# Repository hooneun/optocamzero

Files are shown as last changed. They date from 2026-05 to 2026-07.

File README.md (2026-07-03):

# Optocam Zero

Optocam Zero is a Raspberry Pi Zero based compact digital camera made using off the shelf components. 

I designed Optocam Zero to have a very compact, carry everywhere and have fun sort of camera. As I was inspired by Kodak charmera and similar toy cameras, I wanted it to be feel playful, enjoyable and be intuitive to use. I also aimed to make it relatively easy to build so that others can also build one and have fun with it. That's why all the case parts are easily printable and for the electronics it uses off the shelf components that are easy to find.

exploded view

## Features
- Very compact and easy to carry in your pocket.
- Intuitive and simple camera interface and controls.
- Uses autofocus camera module.
- 8 photo filters included.
- Easy and fast image transfer through custom hotspot interface. Optimized both for mobile and desktop.
- Screen dimming when inactive to preserve battery.
- USB-C charging. Device can be used while charging.
- Interchangable battery.
- Off the shelf/ common components for the electronics.
- Fully 3D printed case parts (apart from fasteners).
- 3D printable TPU protective sleeve and lanyard design is available.
- **NEW** - GIF recording and playback.

<br>

## Specs
- **UPDATE** - Now boots in 5 seconds with the buildroot image.
- **UPDATE** - Consistent 25-30 fps camera preview on the screen.
- 2592x2592px Jpeg image capture. Image saves in the background while preview stays active.
- 240x240px 1.4 inch lcd display.
- Uses 14500 type li-ion battery.
- 70–80 minutes of use per charge.
- Dimensions: 51×71×18mm (excluding camera and screen bump)
  
<br>

## Sample Photos

 
 
 
 

<br>

## How to Build Optocam Zero?

Everything you need to build an Optocam Zero yourself is included in this repo.

All the 3d print files, Required parts list, and detailed step by step build guide can be found under the [hardware](hardware/) folder.

If you're considering building one, check the [BOM](hardware/BOM.md) to get an idea of the cost for required tools and parts.
Also, have a look at the [build guide](hardware/optocamzero-build-guide.pdf), it will give you a clear idea of what the build involves.

<br>

## Hardware

See the [hardware](hardware/) folder for:

- [Bill of materials](hardware/BOM.md).
- [Build guide](hardware/optocamzero-build-guide.pdf) (PDF).
- [Bambu Studio project files](hardware/print-ready/) ready to print for transparent PETG or PETG / PETG-CF.
- [Individual .stls](hardware/stls/) for camera parts.
- [CAD file](hardware/cad/optocamzero_V1.0.step) for customization.

<br>

## Software

See the [software](software/) folder for: 

- Optocam Zero code and installation guide.
- Camera controls information.

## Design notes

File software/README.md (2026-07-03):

# Optocam Zero Firmware Installation and Interface Controls

<br>

## Requirements

- Completed Optocam Zero with the correct components.
- Micro sd card (16GB or larger, A2 type recommended for best performance).
- A computer with internet access.

<br>

## Installation

**1. Download the firmware image**

Download the latest Optocam Zero image (`.img`) from the [releases page](https://github.com/dorukkumkumoglu/optocamzero/releases/latest).

**2. Flash the SD card**

Download Raspberry Pi Imager from [raspberrypi.com/software](https://www.raspberrypi.com/software/) and install it. Select **Raspberry Pi Zero 2W** as the device. Under **Choose OS**, scroll to the bottom and select **Use custom**, then pick the image file you just downloaded.

Select your SD card under **Choose Storage**, then click **Write**. If asked whether to apply OS customisation settings, choose **No**.

**3. First boot**

Insert the SD card into the Pi and power it on. The camera boots to the preview in about 5 seconds and is ready to use.

<br>

<br>

## Interface/ Controls

The device is turned on and off using the power switch on the right side. Reaching the camera preview after turning on the device takes 5 seconds.

Camera focus is set to continuous auto and cannot be adjusted manually. Camera shutter speed and ISO are set to auto and cannot be adjusted manually.

Currently, 8 different photo filters are included. You can switch between them. Color temperature can also be changed.

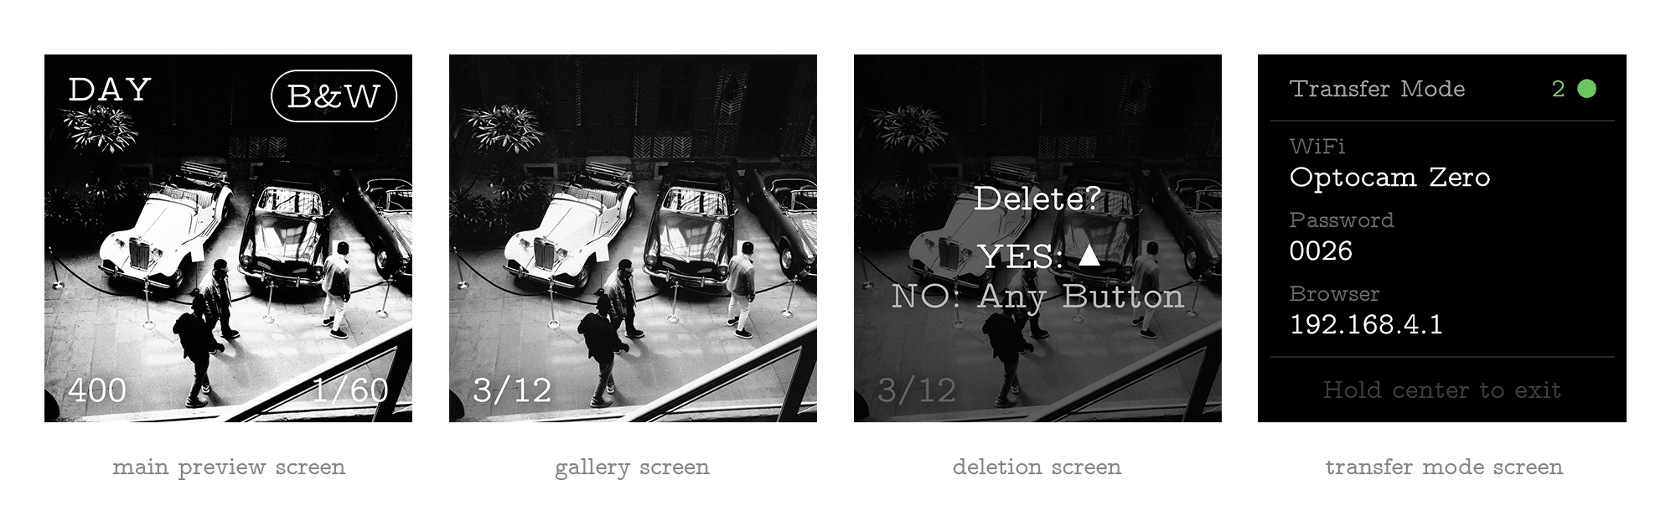
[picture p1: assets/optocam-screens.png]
Camera Screens


### Main camera preview screen controls
- Top left corner displays current color temperature (left-right joystick toggles between different color temperature modes).
- Top right corner displays current photo filter (up-down joystick toggles between different photo filters).
- Bottom left corner displays current ISO.
- Bottom right corner displays current shutter speed.
- A loading circle appears in the bottom center when an image is being saved. Wait for it to disappear before turning off the camera.
- A long press of the shutter button switches between GIF and Photo modes.
- In GIF mode, pressing the shutter button once captures a 10 frame GIF with a duration of 5 seconds. Pressing the shutter button again during capture cancels the recording.

### Gallery controls
- Center joystick button opens the gallery.
- The numbers in the bottom left corner display the photo count and the currently displayed photo number.
- Left-right joystick navigates between photos in the gallery.
- Push joystick up for photo deletion. A confirmation overlay will appear. Push up once more to confirm deletion. Press any other button on the device to cancel.
- To exit the gallery, press the center joystick button or the shutter button. This will return to the main camera preview immediately.

### Transfer mode (Hotspot)
Optocam Zero includes a hotspot mode and photo transfer interface optimized for both mobile and desktop use.
- To activate transfer mode, long press the center joystick button.
- Long press the center joystick button again to exit transfer mode.
- To transfer images, connect your phone or computer to the Wi-Fi network called **Optocam Zero** (find the password on the screen) and open **192.168.4.1** in a browser.
- The dot in the top right corner and the number next to it indicate how many devices are currently connected to the hotspot. The dot turns green when a device is connected.

### Transfer interface (External Device)
After opening the address in a browser, the transfer interface will appear. All photos in your gallery are visible here and can be scrolled and browsed. Below the header logo, the total image count and available free space are displayed.

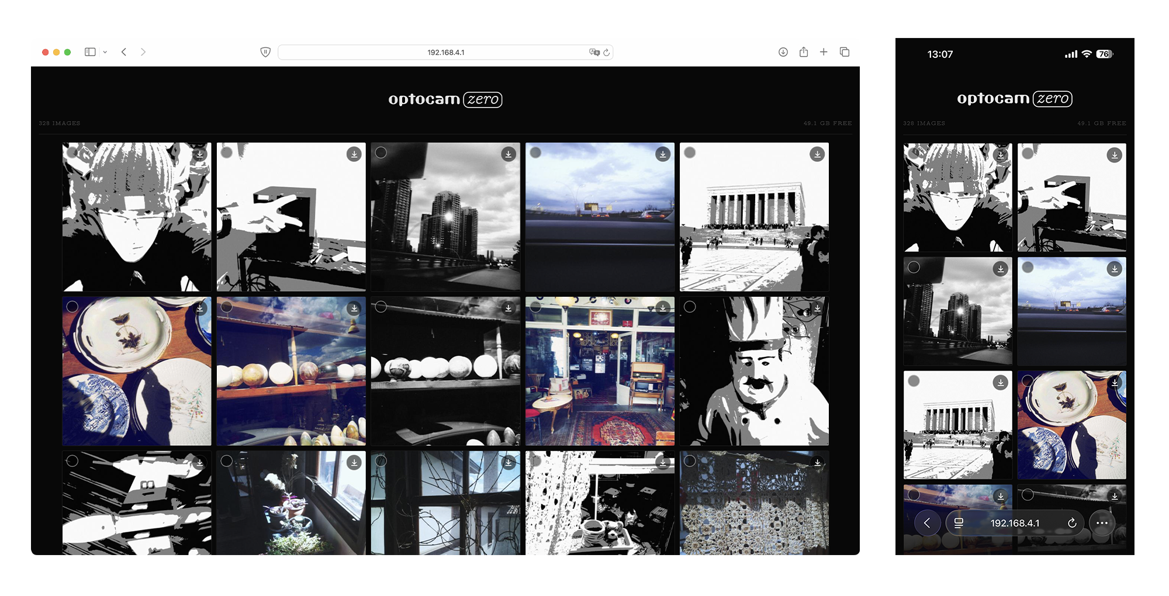
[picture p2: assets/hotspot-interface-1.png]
Transfer Interface


- Photos can be downloaded individually by clicking the download icon in the top right corner of the photo.
- Multiple photos can be selected using the selectors in the top left corner of each image. After selection, you may batch download or delete the selected photos.
- For single image view, click on the image. Use the back button on screen to return, or swipe down on touch devices.
- In single image view, use the left-right arrow keys or swipe left-right to browse between photos.
- To view the full resolution image, click the HQ button in single image view.

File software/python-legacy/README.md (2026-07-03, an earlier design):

> ⚠️ 
> This is the original Raspberry Pi OS / Python version. It still works, but it's no longer the recommended install (slower boot, not updated). For the current firmware installation, see the [software README](../README.md).

<br>

## Requirements

- Completed Optocam Zero with the correct components.
- Micro sd card (16GB or larger, A2 type recommended for best performance).
- A computer with internet access.

<br>

## Installation

**1. Flash the SD card**

Download Raspberry Pi Imager from [raspberrypi.com/software](https://www.raspberrypi.com/software/) and install it. Select **Raspberry Pi Zero 2W** as the device and **Raspberry Pi OS Lite (32-bit) Bookworm** as the OS. You can find it under Raspberry Pi OS (other).

Before flashing, click **Edit Settings** and fill in your hostname, username, password, and WiFi credentials (remember to take note of this info). Go to the Services tab and enable SSH. Click Save, then flash the card.

**2. First boot**

Insert the SD card into the Pi and power it on. Wait about 1-2 minutes for it to boot and connect to your WiFi.

**3. Connect via SSH**

Open Terminal on your computer and run:

```
ssh your-username@your-hostname.local
```

Type `yes` when asked about the fingerprint, then enter your password.

**4. Run the installer**

```
sudo apt-get update
```

```
sudo apt-get install -y git
```

```
git clone https://github.com/dorukkumkumoglu/optocamzero.git && sudo bash optocamzero/software/python-legacy/install.sh
```

Installation takes about 10-15 minutes. The Pi reboots automatically when done and the camera starts immediately.

<br>

## Troubleshooting

**SSH shows "host key changed" error:**
```
ssh-keygen -R your-hostname.local
```

**Camera does not start after reboot:**
```
sudo systemctl status camera-auto.service
```

<br>

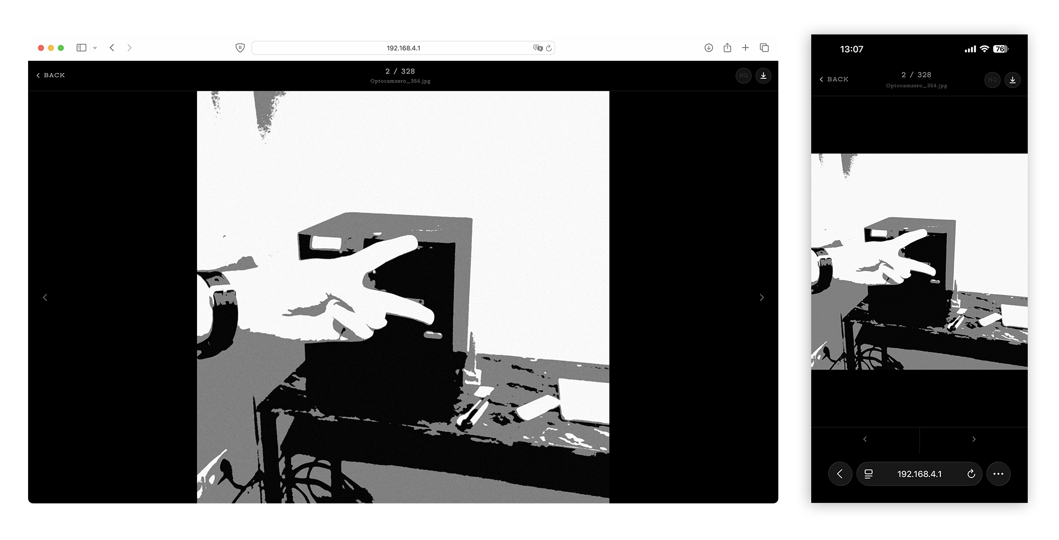
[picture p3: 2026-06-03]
assets/hotspot-interface-2.png

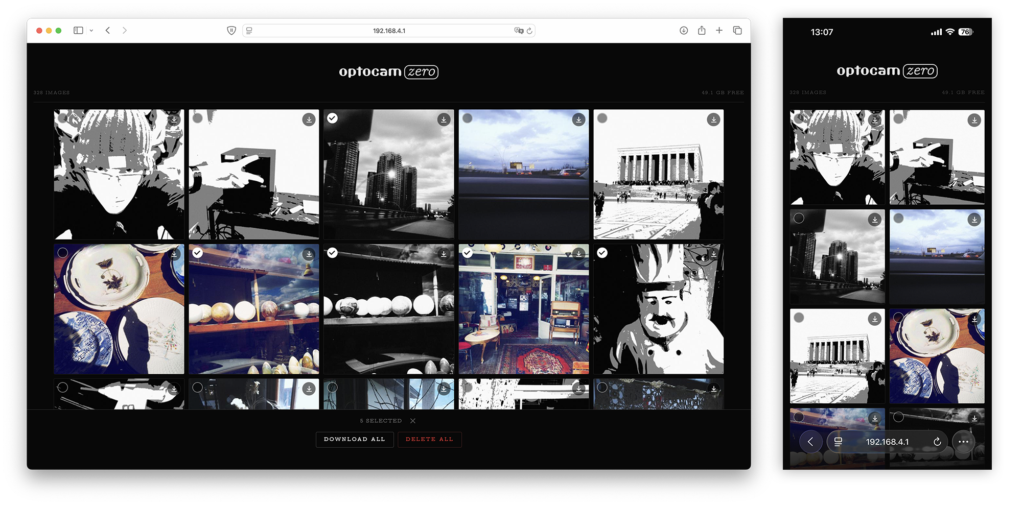
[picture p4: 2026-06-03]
assets/hotspot_interface-1.png

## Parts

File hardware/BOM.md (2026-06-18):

# Optocam Zero V1.0 Bill of Materials
Doruk Kumkumoğlu 2026

<br>

## Electronics

| Item | Qty |
|---|-----|
| [Raspberry Pi Zero 2 W (without header)](https://thepihut.com/products/raspberry-pi-zero-2) | x1 |
| [Raspberry Pi Camera Module 3](https://thepihut.com/products/raspberry-pi-camera-module-3) | x1 |
| Micro SD Card A2 Class — Raspberry Pi or other high quality brands, minimum 16GB | x1 |
| [Waveshare Li-ion Battery HAT for Raspberry Pi](https://www.waveshare.com/li-ion-battery-hat.htm) | x1 |
| [Waveshare 1.3" IPS 240x240 LCD Display HAT for Raspberry Pi](https://www.waveshare.com/1.3inch-lcd-hat.htm) | x1 |
| [Camera Adapter Cable – Raspberry Pi Zero compatible (200mm)](https://thepihut.com/products/camera-adapter-cable-for-raspberry-pi-5) | x1 |
| 14500 Type 3.7V 900 mAh Li-ion Battery | x1 |
| Micro JST 1.25 Pitch 2 Pin Male and Female Connector Set (with 24 AWG cable) — or 24 AWG cable (≥50cm length) | x1 |
| [2×20 Double Row Male GPIO Header](https://thepihut.com/products/break-away-0-1-2x20-pin-strip-dual-male-header) | x1 |
| 0.3mm Ø Enameled Copper Wire (≥30cm length) — or any thin signal cable | x1 |

Note: If you can find non-standard 8-9mm lenght pin headers, use those instead of the standard 2x20 double row header specified in the list.

<br>

## Fasteners

| Item | Qty |
|---|-----|
| M3×16mm Stainless Steel Hex-Drive Flat Head Screw | x4 |
| M2×6mm Screw (comes with the Waveshare Display HAT) | x2 | 
| [M3×4mm×4mm Brass Heat Set Insert](https://www.adafruit.com/product/4255) | x4 |
| 12×3×1mm Neodymium Magnet | x8 |

<br>

## Optional Fasteners

| Item | Qty |
|---|-----|
| M3×6mm Stainless Steel Hex-Drive Flat Head Screw (for lanyard accessory) | x2 |
| M3 Stainless Steel Nut (for lanyard accessory) | x2 |

<br>

## 3D Printed Parts and Materials

| Item | Material | Qty |
|---|---|-----|
| Enclosure | PETG | x1 |
| Back Panel | PETG | x1 |
| Camera Cover | PETG | x1 |
| Camera Circle | PETG | x1 |
| Front Spacer | PETG | x1 |
| Front Panel | PETG | x1 |
| Battery Door | PETG | x1 |
| Battery Level Visor | PETG | x1 |
| On/Off Button | PETG | x1 |
| Joystick Button | PETG | x1 |
| Washer 1mm | PETG | x4 |
| Washer 4mm | PETG | x4 |

<br>

## Optional 3D Printed Parts

| Item | Material | Qty |
|---|---|-----|
| Lanyard Lock Parts | PETG | x1 |
| Camera Sleeve | TPU | x1 |

<br>

## Optional – Cords & Straps

| Item | Qty |
|---|-----|
| Paracord – 1mm Ø, ≥30cm length | x1 |
| Paracord – 4mm Ø, ≥1m length | x1 |

<br>

## Tools

- 3D Printer
- Soldering Iron
- M3 Heat Set Insert Tip For Soldering Iron
- Solder Pump
- Solder
- Flux
- Kapton Tape
- 2mm (M3) Hex Driver
- Utility Knife
- Pliers
- Side Cutter
- Tweezers

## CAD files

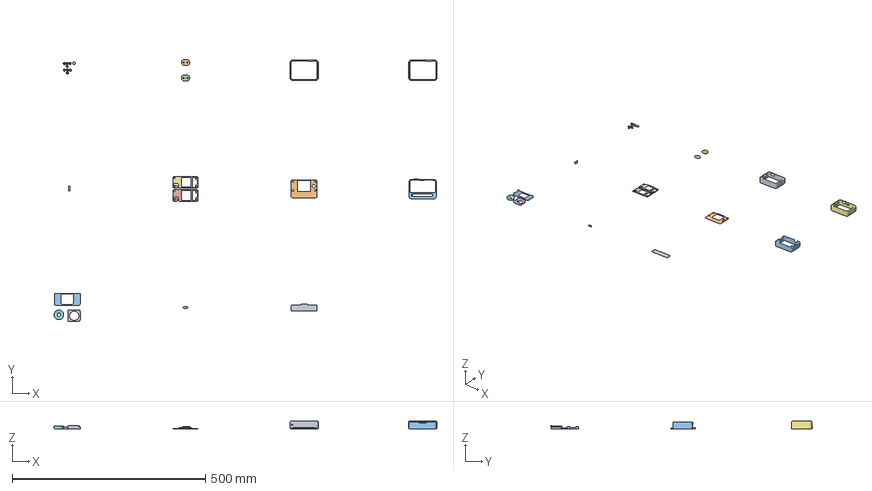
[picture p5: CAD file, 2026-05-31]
hardware/print-ready/optocamzero-transparent_v1.1_bambustudio.3mf
991.7 x 678.8 x 19.5 mm
Case TPU
top
Back Cover
bottom
front-spacer_v1.0.stl
Camera Cover
Front spacer B (For thicker screen)
Camera Circle
Battery Door
Front Panel
Enclosure
washer 4mm x 4
washer 1mm x 4
Joystick Button
On/ Off Button
Battery level visor
Case B

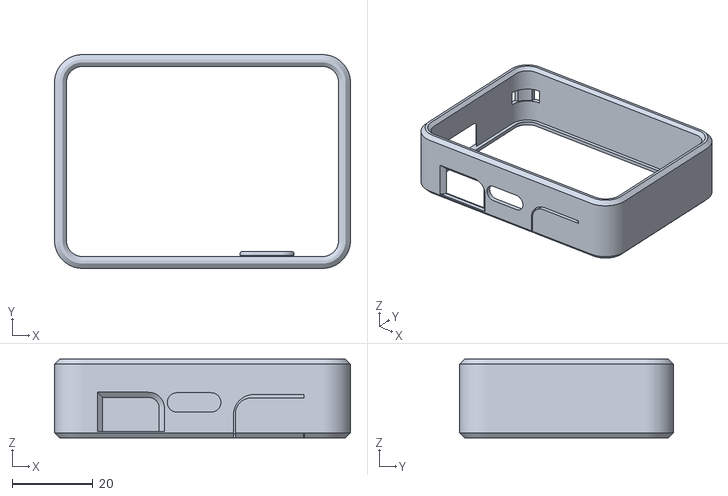
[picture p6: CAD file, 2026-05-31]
hardware/stls/case-b_v1.0.stl
73.4 x 53.0 x 19.5

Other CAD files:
hardware/print-ready/optocamzero_v1.1_bambustudio.3mf

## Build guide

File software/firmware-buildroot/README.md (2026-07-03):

# Optocam Zero Buildroot firmware

Current fast-boot firmware source for Optocam Zero. The older Raspberry Pi OS /
Python version is kept in [`../python-legacy/`](../python-legacy/).

## Contents

- `defconfig/` - Buildroot defconfig for the current firmware image.
- `src/` - native Optocam app sources plus its `Makefile`.
- `package/optocam/` - Buildroot package that cross-compiles and installs the
  native app (`optocam_app` and the `optocam_preview` fallback) to `/usr/bin`.
- `config/` - Raspberry Pi boot, genimage, BusyBox, and board scripts.
- `kernel/` - kernel config fragments.
- `overlay/` - root filesystem overlay.
- `debug/` - optional bring-up scripts.

## Build

These files drop into a Buildroot checkout. The defconfig references in-tree
paths, so copy each file to the location below:

| This repo | Buildroot checkout |
| --- | --- |
| `defconfig/optocam_zero_buildroot_defconfig` | `configs/` |
| `package/optocam/` | `package/optocam/` |
| `src/` (incl. `Makefile`) | `package/optocam/src/` |
| `overlay/` | `board/raspberrypi/overlay/` |
| `kernel/*.fragment` | `board/raspberrypi/` |
| `config/busybox.fragment` | `board/raspberrypi/` |
| `config/post-build.sh`, `config/post-image.sh` | `board/raspberrypizero2w/` |
| `config/config_zero2w.txt`, `config/cmdline.txt`, `config/genimage.cfg.in` | `board/raspberrypizero2w/` |

Register the package by adding one line to Buildroot's `package/Config.in`
(e.g. under the "Hardware handling" or "Miscellaneous" menu):

```
source "package/optocam/Config.in"
```

Then build:

```sh
make optocam_zero_buildroot_defconfig
make
```

This produces `output/images/sdcard.img`. The `optocam` package compiles the
native app against the target's libcamera, libjpeg, and freetype and installs
`/usr/bin/optocam_app` and `/usr/bin/optocam_preview`.

## Runtime Defaults

- Target: Raspberry Pi Zero 2 W + IMX708 camera.
- Photos: `/data/photos`.
- Transfer mode: `Optocam Zero`, `192.168.4.1`, password `0026opto`.

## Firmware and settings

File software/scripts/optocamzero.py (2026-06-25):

#!/usr/bin/env python3
import sys
import time
_script_start = time.time()
def log(msg):
    sys.stderr.write(f"[{time.time() - _script_start:.2f}s] {msg}\n")
    sys.stderr.flush()
log("Script file started")

# ── Lazy-av shim ──────────────────────────────────────────────────────────────
# picamera2 unconditionally `import av` (PyAV/ffmpeg) for its video encoders,
# which costs ~2.25s at import (loading libavcodec/format/util/swscale). The
# Optocam only does stills + manually-assembled GIFs and never touches a
# picamera2 encoder, so we install a lazy stand-in for `av`: importing it is
# free, and the real ffmpeg libraries only load if something actually accesses
# an attribute (which never happens here). Saves ~2.5s of cold-boot time.
import types as _types
import importlib as _importlib
class _LazyAv(_types.ModuleType):
    def __getattr__(self, name):
        del sys.modules['av']                       # drop the stub…
        real = _importlib.import_module('av')       # …load the genuine PyAV…
        return getattr(real, name)                  # …and delegate.
if 'av' not in sys.modules:
    sys.modules['av'] = _LazyAv('av')
log("lazy-av shim installed")
# ──────────────────────────────────────────────────────────────────────────────

import RPi.GPIO as GPIO
log("GPIO imported")
import pigpio
log("pigpio imported")
import spidev
log("spidev imported")
import threading
log("threading imported")

# Preload the two heavy modules that are NOT on the first-preview path —
# picamera2 (~1.2s) and PIL.Image — on a background thread so they overlap with
# numpy + display init on the main thread. picamera2 is only used in main() after
# the join; PIL.Image is only touched by HUD/overlay code (warm-overlays thread),
# which runs well after the join. numpy stays on the main thread because the
# module-level RGB565 LUTs below need it immediately.
Image = None  # populated by the preload thread before any overlay code runs
def _preload_heavy():
    global Image
    import picamera2  # noqa: F401 — populates sys.modules for the instant import in main()
    from PIL import Image as _Image
    Image = _Image
_preload_thread = threading.Thread(target=_preload_heavy, daemon=True)
_preload_thread.start()
log("heavy-preload thread started (picamera2 + PIL)")

import os
log("os imported")
import numpy as np
log("numpy imported")
import gc
import subprocess
log("All imports done")

# ── Early-start readiness waits ───────────────────────────────────────────────
# camera-auto.service starts before udev coldplug finishes, so the heavy imports
# above (numpy, picamera2, PIL) overlap kernel device bring-up instead of running
# serially after it. The trade-off: the device nodes below may not exist yet when
# we reach them, so block here until they do rather than crashing on absent hardware.
def _wait_for_path(path, timeout=30):
    end = time.time() + timeout
    while not os.path.exists(path):
        if time.time() > end:
            log(f"WARN: timed out waiting for {path}")
            return False
        time.sleep(0.02)
    return True

def connect_pigpiod(timeout=30):
    """pigpiod may not be up yet (it also waits on gpiomem). Retry until it is."""
    end = time.time() + timeout
    while True:
        pi = pigpio.pi()
        if pi.connected:
            return pi
        pi.stop()
        if time.time() > end:
            log("WARN: pigpiod connect timed out")
            return pi
        time.sleep(0.1)

_wait_for_path('/dev/gpiomem')      # RPi.GPIO needs this
_wait_for_path('/dev/spidev0.0')    # SPI display needs this
log("hardware nodes ready")
# Force clean GPIO
GPIO.setwarnings(False)
GPIO.setmode(GPIO.BCM)
for pin in [21, 20, 5, 26, 13, 6, 19]:
    try:
        GPIO.remove_event_detect(pin)
    except:
        pass
GPIO.cleanup()
time.sleep(0.2)
# Pins
RST_PIN = 27
DC_PIN = 25
BL_PIN = 24
BUTTON_CAPTURE = 21
BUTTON_PREVIEW = 20
JOYSTICK_LEFT = 5
JOYSTICK_RIGHT = 26
JOYSTICK_PRESS = 13
JOYSTICK_UP = 6
JOYSTICK_DOWN = 19
# Setup GPIO
GPIO.setmode(GPIO.BCM)
GPIO.setup(RST_PIN, GPIO.OUT)
GPIO.setup(DC_PIN, GPIO.OUT)
GPIO.setup(BL_PIN, GPIO.OUT)
_pi = connect_pigpiod()
_pi.set_PWM_frequency(BL_PIN, 1000)
# Keep the backlight OFF until the splash is actually drawn — otherwise it lights
# the uninitialised (white) panel for ~2s during boot before the splash appears.
_pi.set_PWM_dutycycle(BL_PIN, 0)
GPIO.setup(BUTTON_PREVIEW, GPIO.IN, pull_up_down=GPIO.PUD_UP)
GPIO.setup(BUTTON_CAPTURE, GPIO.IN, pull_up_down=GPIO.PUD_UP)
GPIO.setup(JOYSTICK_LEFT, GPIO.IN, pull_up_down=GPIO.PUD_UP)
GPIO.setup(JOYSTICK_RIGHT, GPIO.IN, pull_up_down=GPIO.PUD_UP)
GPIO.setup(JOYSTICK_PRESS, GPIO.IN, pull_up_down=GPIO.PUD_UP)
GPIO.setup(JOYSTICK_UP, GPIO.IN, pull_up_down=GPIO.PUD_UP)
GPIO.setup(JOYSTICK_DOWN, GPIO.IN, pull_up_down=GPIO.PUD_UP)
# SPI
spi = spidev.SpiDev()
spi.open(0, 0)
spi.max_speed_hz = 100000000
spi.mode = 0
spi.bits_per_word = 8
# Locks
camera_lock = threading.RLock()
display_lock = threading.Lock()
# Camera configuration cache
class CameraConfigCache:
    def __init__(self, picam2):
        self.preview_config = picam2.create_preview_configuration(
            main={"size": (240, 240), "format": "RGB888"},
            buffer_count=3,
            queue=False,
            controls={"AfMode": 2, "AfSpeed": 1, "FrameDurationLimits": (100, 25000)}
        )
        self._picam2 = picam2
        self.capture_config = None
        self.gif_config = None

    def get_capture_config(self):
        if self.capture_config is None:
            self.capture_config = self._picam2.create_still_configuration(
                main={"size": (2592, 2592), "format": "RGB888"},
                buffer_count=2
            )
        return self.capture_config

    def get_gif_config(self):
        # 640x640 stream used only while recording a GIF. Built lazily so it
        # never costs anything until the first recording. Continuous AF, frame
        # duration capped so live frames keep flowing during the countdown.
        if self.gif_config is None:
            self.gif_config = self._picam2.create_preview_configuration(
                main={"size": (640, 640), "format": "RGB888"},
                buffer_count=4,
                controls={"AfMode": 2, "AfSpeed": 1, "FrameDurationLimits": (33333, 100000)}
            )
        return self.gif_config
config_cache = None
FONT_PATH = "/home/dkumkum/cmunvt.ttf"

# Shadow cache for preview overlays — only regenerated when value changes
_shadow_cache = {}

# Fully-assembled HUD overlay cache — keyed on the values that define it, so a
# steady scene reuses the composited shadow layer instead of rebuilding it
# (skips ~4 full-frame alpha_composites per preview frame).
_hud_overlay_cache = {"key": None, "img": None}

def make_text_shadow(text, x, y, font):
    from PIL import ImageDraw, ImageFilter
    shadow = Image.new("RGBA", (240, 240), (0, 0, 0, 0))
    ImageDraw.Draw(shadow).text((x, y), text, font=font, fill=(0, 0, 0, 250))
    return shadow.filter(ImageFilter.GaussianBlur(radius=4))

_STANDARD_ISO = [100, 125, 160, 200, 250, 320, 400, 500, 640, 800, 1000, 1250, 1600]

AWB_MODES = [
    (1, "Tungsten",    "TNG"),
    (2, "Fluorescent", "FLR"),
    (3, "Indoor",      "IND"),
    (4, "Daylight",    "DAY"),
    (5, "Cloudy",      "CLD"),
]

# (microseconds, display string)
_STANDARD_SHUTTERS = [
    (125, "1/8000"), (156, "1/6400"), (200, "1/5000"), (250, "1/4000"),
    (313, "1/3200"), (400, "1/2500"), (500, "1/2000"), (625, "1/1600"),
    (800, "1/1250"), (1000, "1/1000"), (1250, "1/800"), (1563, "1/640"),
    (2000, "1/500"), (2500, "1/400"), (3125, "1/320"), (4000, "1/250"),
    (5000, "1/200"), (6250, "1/160"), (8000, "1/125"), (10000, "1/100"),
    (12500, "1/80"), (16667, "1/60"), (20000, "1/50"), (25000, "1/40"),
    (33333, "1/30"), (40000, "1/25"), (50000, "1/20"), (66667, "1/15"),
    (100000, "1/10"), (125000, "1/8"), (166667, "1/6"), (200000, "1/5"),
    (250000, "1/4"), (333333, "1/3"), (500000, "1/2"), (1000000, "1\""),
]

def nearest_standard_iso(gain):
    iso = gain * 100
    return min(_STANDARD_ISO, key=lambda s: abs(s - iso))

def nearest_standard_shutter(exp_us):
    return min(_STANDARD_SHUTTERS, key=lambda s: abs(s[0] - exp_us))[1]

def get_cached_shadow(key, text, x, y, font):
    if _shadow_cache.get(key) != text:
        _shadow_cache[key] = text
        _shadow_cache[key + "_img"] = make_text_shadow(text, x, y, font)
    return _shadow_cache[key + "_img"]

# ── Animated centre labels (filter name, "GIF Mode", toasts) ────────────────
# Each label is rendered once into a cached sprite (blurred shadow + white text),
# then composited every frame with an eased fade + slight scale "pop". Kept
# separate from the cached static HUD overlay so it animates without invalidating
# that cache — steady-state cost is unchanged; the extra work only runs while a
# label is on screen.
_centre_msg_sprite_cache = {}

def get_centre_msg_sprite(text):
    if text in _centre_msg_sprite_cache:
        return _centre_msg_sprite_cache[text]
    from PIL import ImageDraw, ImageFilter
    font = load_font(25)
    shadow = Image.new("RGBA", (240, 240), (0, 0, 0, 0))
    white  = Image.new("RGBA", (240, 240), (0, 0, 0, 0))
    wd = ImageDraw.Draw(white)
    b = wd.textbbox((0, 0), text, font=font)
    mx = (240 - (b[2] - b[0])) // 2 - b[0]
    my = (240 - (b[3] - b[1])) // 2 - b[1]
    ImageDraw.Draw(shadow).text((mx, my), text, font=font, fill=(0, 0, 0, 250))
    shadow = shadow.filter(ImageFilter.GaussianBlur(radius=4))
    wd.text((mx, my), text, font=font, fill=(255, 255, 255, 255))
    sprite = Image.alpha_composite(shadow, white)
    _centre_msg_sprite_cache[text] = sprite
    return sprite

def _ease_out_back(t, c1=1.9):
    """Ease-out with an overshoot past 1.0 — the bounce (bigger c1 = more bounce)."""
    c3 = c1 + 1
    return 1 + c3 * (t - 1) ** 3 + c1 * (t - 1) ** 2

def _ease_centre_msg(age, dur):
    """(alpha, scale): short fade in/out; scale matches the original version —
    a gentle 0.80→1.0 ease-out, no overshoot."""
    A_IN, A_OUT, S_IN = 0.12, 0.18, 0.18
    if age < A_IN:
        alpha = 1 - (1 - age / A_IN) ** 3
    elif age > dur - A_OUT:
        t = max(0.0, (dur - age) / A_OUT)
        alpha = t * t
    else:
        alpha = 1.0
    if age < S_IN:
        t = age / S_IN
        scale = 0.80 + 0.20 * (1 - (1 - t) ** 3)
    else:
        scale = 1.0
    return alpha, scale

def render_centre_msg(base_rgb, text, age, dur):
    """Composite the centre label with a short fade + a scale bounce."""
    a, s = _ease_centre_msg(age, dur)
    sprite = get_centre_msg_sprite(text)
    if abs(s - 1.0) > 0.005:                # handles both shrink (<1) and overshoot (>1)
        sw = max(1, int(240 * s))
        small = sprite.resize((sw, sw), Image.BILINEAR)
        sprite2 = Image.new("RGBA", (240, 240), (0, 0, 0, 0))
        off = (240 - sw) // 2
        sprite2.paste(small, (off, off))
        sprite = sprite2
    if a < 0.999:
        faded = sprite.copy()
        faded.putalpha(sprite.getchannel("A").point(lambda p: int(p * a)))
        sprite = faded
    return Image.alpha_composite(base_rgb.convert("RGBA"), sprite).convert("RGB")

# Filter pill: the slightest bounce when the filter changes (subtle overshoot,
# no opacity change). Pulled out of the cached overlay only while popping.
PILL_POP_DUR = 0.30

def _pill_pop_scale(age):
    t = min(1.0, max(0.0, age / PILL_POP_DUR))
    return 0.90 + 0.10 * _ease_out_back(t)        # 0.90 → ~1.01 → 1.0 (very subtle)

def render_pill_pop(base_rgb, indicator, scale):
    """Composite the filter indicator scaled around its own centre."""
    bbox = indicator.getbbox()
    if bbox is None or abs(scale - 1.0) < 0.005:
        return Image.alpha_composite(base_rgb.convert("RGBA"), indicator).convert("RGB")
    cx = (bbox[0] + bbox[2]) / 2.0
    cy = (bbox[1] + bbox[3]) / 2.0
    sw = max(1, int(240 * scale))
    resized = indicator.resize((sw, sw), Image.BILINEAR)
    canvas = Image.new("RGBA", (240, 240), (0, 0, 0, 0))
    canvas.paste(resized, (int(round(cx * (1 - scale))), int(round(cy * (1 - scale)))))
    return Image.alpha_composite(base_rgb.convert("RGBA"), canvas).convert("RGB")

# AWB label sprite (top-left) — cached per (text, font size). Reused by the
# white-balance transition: the label scale-pops whenever its text changes,
# i.e. on an AWB change and again when the full name collapses to the abbrev.
_awb_sprite_cache = {}
AWB_POP_DUR = 0.30      # gentle, matches the filter pill

def get_awb_sprite(text, font_size):
    key = (text, font_size)
    if key in _awb_sprite_cache:
        return _awb_sprite_cache[key]
    from PIL import ImageDraw, ImageFilter
    font = load_font(font_size)
    shadow = Image.new("RGBA", (240, 240), (0, 0, 0, 0))
    white  = Image.new("RGBA", (240, 240), (0, 0, 0, 0))
    wd = ImageDraw.Draw(white)
    b = wd.textbbox((0, 0), text, font=font)
    ax, ay = 15, 15 - b[1]
    ImageDraw.Draw(shadow).text((ax, ay), text, font=font, fill=(0, 0, 0, 250))
    shadow = shadow.filter(ImageFilter.GaussianBlur(radius=4))
    wd.text((ax, ay), text, font=font, fill=(255, 255, 255, 255))
    sprite = Image.alpha_composite(shadow, white)
    _awb_sprite_cache[key] = sprite
    return sprite

def _awb_pop_scale(age, full):
    t = min(1.0, max(0.0, age / AWB_POP_DUR))
    e = _ease_out_back(t)
    if full:
        return 0.94 + 0.06 * e     # long name: even more subtle
    return 0.90 + 0.10 * e         # abbreviation: gentle, like the filter pill

# Filter indicator circle — cached per filter name, built once on first use
_indicator_cache = {}

def get_filter_indicator(filter_name):
    if filter_name in _indicator_cache:
        return _indicator_cache[filter_name]
    from PIL import ImageDraw, ImageFilter
    # Rendered at SxS supersample then scaled down with LANCZOS so the circle /
    # pill outline is anti-aliased. Cached per filter, so this runs once per
    # filter — the preview loop only ever composites the finished 240px layer,
    # so there is no per-frame cost and the fps is unchanged.
    S   = 3
    big = 240 * S
    pad = 10 * S
    r   = 17 * S
    cx  = big - pad - r
    cy  = pad + r
    font = load_font(24 * S)

    # Build shadow and white layers separately, then composite — same approach as HUD text
    shadow = Image.new("RGBA", (big, big), (0, 0, 0, 0))
    white  = Image.new("RGBA", (big, big), (0, 0, 0, 0))
    sd = ImageDraw.Draw(shadow)
    wd = ImageDraw.Draw(white)

    # Filters with multi-char labels use a pill; single-char filters use a circle
    _PILL_LABELS = {"B&W": "B&W", "TRI-X": "TX", "Film Standard": "FS"}

    if filter_name in _PILL_LABELS:
        label  = _PILL_LABELS[filter_name]
        tb     = wd.textbbox((0, 0), label, font=font)
        h_pad  = 10 * S
        pill_h = r * 2
        pill_w = (tb[2] - tb[0]) + h_pad * 2
        x1, y0 = big - pad, pad
        x0, y1 = x1 - pill_w, y0 + pill_h
        cr  = pill_h // 2
        pcx = (x0 + x1) // 2
        pcy = (y0 + y1) // 2
        tx  = pcx - (tb[0] + tb[2]) // 2
        ty  = pcy - (tb[1] + tb[3]) // 2
        sd.rounded_rectangle([x0, y0, x1, y1], radius=cr, outline=(0, 0, 0, 250), width=2 * S)
        sd.text((tx, ty), label, font=font, fill=(0, 0, 0, 250))
        wd.rounded_rectangle([x0, y0, x1, y1], radius=cr, outline=(255, 255, 255, 255), width=1 * S)
        wd.text((tx, ty), label, font=font, fill=(255, 255, 255, 255))
    else:
        label = filter_name[0]
        tb = wd.textbbox((0, 0), label, font=font)
        tx = cx - (tb[0] + tb[2]) // 2
        ty = cy - (tb[1] + tb[3]) // 2
        if label in ("D", "P", "L", "N"):
            tx += S
        sd.ellipse([cx-r, cy-r, cx+r, cy+r], outline=(0, 0, 0, 250), width=2 * S)
        sd.text((tx, ty), label, font=font, fill=(0, 0, 0, 250))
        wd.ellipse([cx-r, cy-r, cx+r, cy+r], outline=(255, 255, 255, 255), width=1 * S)
        wd.text((tx, ty), label, font=font, fill=(255, 255, 255, 255))

    shadow = shadow.filter(ImageFilter.GaussianBlur(radius=4 * S))
    layer  = Image.alpha_composite(shadow, white).resize((240, 240), Image.LANCZOS)
    _indicator_cache[filter_name] = layer
    return layer

# "GIF" badge shown while GIF mode is armed, with a marching-dashes outline.
# A small set of phase variants is pre-rendered once (each with its own blur),
# then cycled per frame — so the animation costs nothing extra at draw time.
_GIF_PILL_PHASES   = 2     # number of pre-rendered dash offsets (one loop)
_GIF_PILL_MARCH_HZ = 4     # phases advanced per second → marching speed
_gif_indicator_phases = None

def _trace_capsule_perimeter(x0, y0, x1, y1, cr, step=1.5):
    """Ordered points around a horizontal capsule (pill) perimeter, used to lay
    dashes along the outline."""
    import math
    pts = []
    xa, xb = x0 + cr, x1 - cr
    cyc = y0 + cr
    d = xa                                   # top edge, left → right
    while d <= xb:
        pts.append((d, y0)); d += step
    a = -math.pi / 2                         # right end semicircle
    while a <= math.pi / 2:
        pts.append((xb + cr * math.cos(a), cyc + cr * math.sin(a))); a += step / cr
    d = xb                                   # bottom edge, right → left
    while d >= xa:
        pts.append((d, y1)); d -= step
    a = math.pi / 2                          # left end semicircle
    while a <= 3 * math.pi / 2:
        pts.append((xa + cr * math.cos(a), cyc + cr * math.sin(a))); a += step / cr
    return pts

def _draw_dashed_path(draw, pts, phase, dash, gap, width, fill):
    """Draw a dashed line along an ordered, closed list of points. `phase` shifts
    the dash pattern along the path (marching ants)."""
    import math
    period = dash + gap
    acc = 0.0
    for p, q in zip(pts, pts[1:] + pts[:1]):
        if ((acc + phase) % period) < dash:
            draw.line([p, q], fill=fill, width=width)
        acc += math.hypot(q[0] - p[0], q[1] - p[1])

def _build_gif_indicator_phases():
    # Rendered at SxS supersample then scaled down with LANCZOS so the dashes
    # come out smooth and anti-aliased instead of jagged. One-time cost.
    from PIL import ImageDraw, ImageFilter
    S   = 3
    big = 240 * S
    font = load_font(24 * S)
    label = "GIF"
    tmp = ImageDraw.Draw(Image.new("RGBA", (1, 1)))
    tb = tmp.textbbox((0, 0), label, font=font)
    # Sits directly under the filter pill (top-right), sharing its right edge.
    pad    = 10 * S
    pill_h = 34 * S
    pill_w = (tb[2] - tb[0]) + 20 * S
    x1 = big - pad
    x0 = x1 - pill_w
    y0 = pad + pill_h + 8 * S
    y1 = y0 + pill_h
    cr = pill_h // 2
    tx = x0 + (pill_w - (tb[0] + tb[2])) // 2
    ty = y0 + (pill_h - (tb[1] + tb[3])) // 2
    pts = _trace_capsule_perimeter(x0, y0, x1, y1, cr, step=2.0)
    dash, gap = 6 * S, 5 * S
    period = dash + gap
    layers = []
    for k in range(_GIF_PILL_PHASES):
        phase = period * k / _GIF_PILL_PHASES   # full pattern shift over one loop
        shadow = Image.new("RGBA", (big, big), (0, 0, 0, 0))
        white  = Image.new("RGBA", (big, big), (0, 0, 0, 0))
        sd = ImageDraw.Draw(shadow)
        wd = ImageDraw.Draw(white)
        _draw_dashed_path(sd, pts, phase, dash, gap, 3 * S, (0, 0, 0, 250))
        _draw_dashed_path(wd, pts, phase, dash, gap, 2 * S, (255, 255, 255, 255))
        sd.text((tx, ty), label, font=font, fill=(0, 0, 0, 250))
        wd.text((tx, ty), label, font=font, fill=(255, 255, 255, 255))
        shadow = shadow.filter(ImageFilter.GaussianBlur(radius=4 * S))
        layer = Image.alpha_composite(shadow, white).resize((240, 240), Image.LANCZOS)
        layers.append(layer)
    return layers

def get_gif_mode_indicator(phase_index=0):
    global _gif_indicator_phases
    if _gif_indicator_phases is None:
        _gif_indicator_phases = _build_gif_indicator_phases()
    return _gif_indicator_phases[phase_index % _GIF_PILL_PHASES]

_font_cache = {}  # v2: cache loaded fonts so TTF isn't re-opened every frame
_font_warned = False
def load_font(size):
    global _font_warned
    if size in _font_cache:
        return _font_cache[size]
    from PIL import ImageFont
    try:
        _font_cache[size] = ImageFont.truetype(FONT_PATH, size)
    except (OSError, IOError) as e:
        # Bitmap default has no TTF dependency and will always load; surface
        # the reason once so silent fallbacks don't hide misconfiguration
        # (e.g. Pillow built without freetype, or the TTF missing on disk).
        if not _font_warned:
            log(f"TTF load failed ({FONT_PATH}): {e!r} — using bitmap default")
            _font_warned = True
        _font_cache[size] = ImageFont.load_default()
    return _font_cache[size]

# ── Filters ────────────────────────────────────────────────────────────────
FILTERS = ["Film Standard", "Punch", "B&W", "Deep", "Sand", "Eterna", "TRI-X", "Cutout", "No Filter"]

def _make_lut(points):
    x = [p[0] for p in points]
    y = [p[1] for p in points]
    return np.interp(np.arange(256), x, y).clip(0, 255).astype(np.uint8)

# Base tone curves
_BASE_CURVES = {
    "B&W":        _make_lut([(0,0),(64,16),(128,160),(192,242),(255,255)]),   # steeper S — deeper blacks, brighter whites
    "Punch":      _make_lut([(0,0),(64,52),(128,148),(192,212),(255,242)]),   # pure blacks, highlights pulled down
    "Sand":       _make_lut([(0,0),(64,50),(128,132),(192,205),(255,255)]),   # gentle S for sepia
    "Deep":       _make_lut([(0,30),(64,70),(128,152),(192,222),(255,255)]),
    "Eterna":        _make_lut([(0,30),(64,78),(128,128),(192,172),(255,215)]),  # very flat, heavy lifted blacks, compressed highlights
    "Film Standard": _make_lut([(0,18),(64,55),(128,140),(192,210),(255,252)]),  # Classic Neg: lifted blacks, strong S, compressed highlights
}

# Channel LUTs — built manually per filter
_CHANNEL_LUTS = {}
_v = np.arange(256, dtype=np.float32)
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

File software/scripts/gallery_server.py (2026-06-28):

#!/usr/bin/env python3
"""OptoCam Gallery Server — serves photos over WiFi hotspot"""
import os
import io
import json
import time
import zipfile
import tempfile
from flask import Flask, send_from_directory, render_template_string, Response, request

PHOTOS_DIR = "/home/dkumkum/photos"

MEDIA_EXTS = (".jpg", ".gif")

app = Flask(__name__)

# token -> {"sent": int, "total": int, "ts": float} — live zip download progress.
DOWNLOAD_PROGRESS = {}


def capture_number_of(filename):
    """Numeric id from Optocamzero_<n>.<ext>, or None. Shared ordering across
    photos (.jpg) and GIFs (.gif)."""
    if not filename.startswith("Optocamzero_"):
        return None
    stem = filename[len("Optocamzero_"):]
    dot = stem.rfind(".")
    if dot == -1:
        return None
    num, ext = stem[:dot], stem[dot:].lower()
    if ext in MEDIA_EXTS and num.isdigit():
        return int(num)
    return None


def list_media():
    """All media files (photos + GIFs) newest-first."""
    if not os.path.exists(PHOTOS_DIR):
        return []
    files = [f for f in os.listdir(PHOTOS_DIR) if capture_number_of(f) is not None]
    files.sort(key=lambda f: capture_number_of(f), reverse=True)
    return files

HTML = """<!DOCTYPE html>
<html>
<head>
<meta name="viewport" content="width=device-width, initial-scale=1, maximum-scale=1">
<title>Optocam Zero</title>
<style>
@font-face {
    font-family: 'CamFont';
    src: url('/font/cmunvt.ttf') format('truetype');
}
* { margin: 0; padding: 0; box-sizing: border-box; }
body {
    background: #080808;
    color: #d0d0d0;
    font-family: 'CamFont', 'Courier New', monospace;
    padding: 14px;
    -webkit-tap-highlight-color: transparent;
    overscroll-behavior: none;
}
/* While the viewer is open, make the page background black too, so no gray
   (body color) shows in any strip the fixed viewer doesn't cover on iOS. */
body:has(#viewer.open) { background: #000; }
header {
    border-bottom: 1px solid #1e1e1e;
    padding-top: 11px;    /* less top than bottom to offset the 14px body padding above */
    padding-bottom: 25px;
    margin-bottom: 14px;
    /* Stretch past the body's 14px padding so the divider spans the full width. */
    margin-left: -14px;
    margin-right: -14px;
    display: flex;
    flex-direction: column;
    align-items: center;
}
.logo { height: 30px; width: auto; display: block; }
@media (min-width: 768px) {
    header { padding-top: 16px; padding-bottom: 30px; }
}
.meta {
    display: flex;
    gap: 18px;
    font-size: 12px;
    color: #555;
    letter-spacing: 1px;
}
/* Counter and free-space share one size (the counter's). */
.meta span { font-size: 12px; }
/* Row holding the grouped meta (left) and the grid-density toggle (right). */
.meta-row {
    display: flex;
    align-items: center;
    justify-content: space-between;
    gap: 12px;
}
.grid {
    display: grid;
    grid-template-columns: 1fr 1fr;
    gap: 8px;
    padding-bottom: 50px;
}
@media (min-width: 768px) {
    .grid { grid-template-columns: repeat(5, 1fr); }   /* desktop default */
    /* Gap tightens as density increases: 5-col 8px, 6-col 7px, 7-col 6px. */
    .grid.dcols-5 { grid-template-columns: repeat(5, 1fr); }
    .grid.dcols-6 { grid-template-columns: repeat(6, 1fr); gap: 7px; }
    .grid.dcols-7 { grid-template-columns: repeat(7, 1fr); gap: 6px; }
    /* Uniform control sizing across all desktop densities:
       21px selection ring, 22px download icon. */
    .grid .sel-circle::before { width: 21px; height: 21px; }
    .grid .item.sel .sel-circle::after { top: 17.5px; left: 17.5px; }
    .grid .dl-icon { width: 22px; height: 22px; }
}
@media (min-width: 1200px) {
    .grid {
        max-width: 1400px;
        margin: 0 auto;
    }
}
/* Stop iOS Safari from hijacking long-press on thumbnails (the image
   callout/"Save Image" menu, magnified preview and image drag) — otherwise it
   cancels the touch and the glide-to-select can't run. */
.grid, .grid * {
    -webkit-touch-callout: none;
    -webkit-user-select: none;
    user-select: none;
}
.img-btn img { -webkit-user-drag: none; }
.item {
    background: #101010;
    border: 1px solid #1a1a1a;
    border-radius: 3px;
    overflow: hidden;
    cursor: pointer;
}
.item.sel { border-color: #1a1a1a; }
.img-wrap { position: relative; }
/* Tint selected thumbnails — overlay sits above the image but below the
   dot / download / GIF-badge controls (z-index 2). */
.item.sel .img-wrap::after {
    content: '';
    position: absolute;
    inset: 0;
    background: rgba(0, 0, 0, 0.4);
    pointer-events: none;
    z-index: 1;
}
.img-btn {
    display: block;
    width: 100%;
    padding: 0;
    border: none;
    background: none;
    cursor: pointer;
}
.img-btn img {
    width: 100%;
    aspect-ratio: 1 / 1;
    object-fit: cover;
    display: block;
}
.sel-circle {
    position: absolute;
    /* Anchored to the very corner so there's no dead margin around the dot;
       the ring (::before) is offset inward to keep its visual position. */
    top: 0;
    left: 0;
    /* Visible ring stays 23px (the ::before); the button itself is larger to
       give a bigger, easier-to-hit tap target without changing the look. */
    width: 54px;
    height: 54px;
    border-radius: 50%;
    border: none;
    background: transparent;
    cursor: pointer;
    z-index: 2;
    transition: none;
    touch-action: pan-y;   /* vertical drags still scroll; horizontal glide selects */
}
.sel-circle::before {
    content: '';
    position: absolute;   /* offset inward from the corner-anchored button */
    top: 7px;
    left: 7px;
    width: 23px;
    height: 23px;
    border-radius: 50%;
    border: 1.5px solid rgba(255,255,255,0.45);
    background: rgba(0,0,0,0.45);
    transition: background 0.12s, border-color 0.12s;
    box-sizing: border-box;
}
.item.sel .sel-circle::before {
    background: #fff;
    border-color: #fff;
}
.item.sel .sel-circle::after {
    content: '';
    position: absolute;
    /* Centered on the 23px ring (offset 7px inward from the button corner). */
    top: 18.5px;
    left: 18.5px;
    width: 5px;
    height: 9px;
    border: 2px solid #000;
    border-top: none;
    border-left: none;
    transform: translate(-60%, -65%) rotate(45deg);
}
.dl-icon {
    position: absolute;
    top: 7px;
    right: 7px;
    width: 24px;
    height: 24px;
    background: rgba(0,0,0,0.6);
    border: none;
    border-radius: 50%;
    display: flex;
    align-items: center;
    justify-content: center;
    text-decoration: none;
    z-index: 2;
}
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

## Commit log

2026-05-31 add new case version
    [case-b_v1.0.stl]
2026-05-31 add case version B
    V1.1 includes a new case version with a hole for battery indicator. Use this if the TPU material is not transparent enough.
    [optocamzero-transparent_v1.1_bambustudio.3mf, optocamzero_v1.1_bambustudio.3mf]
2026-06-19 Add GIF recording/playback, HUD animations, and performance fixes
    Camera (optocamzero.py):
    - GIF mode: long-press shutter to arm, tap to record a 640x640 10-frame
    GIF (2 fps over 5s) with on-screen frame counter; shutter cancels mid-record.
    - Device gallery plays GIFs back; shared photo/GIF numbering.
    - HUD animations: filter-name / AWB / mode labels fade+scale in; filter pill
    and AWB abbreviation pop on change; anti-aliased filter pills.
    - Performance: fused RGB565 LUT, cached HUD overlay assembly, trimmed capture
    settle sleeps + AF timeout 1.0->0.5s, backlight stays off until splash
    (removes white boot flash).
    Web gallery (gallery_server.py):
    - GIFs listed and animated in grid + v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
    [gallery_server.py, optocamzero.py]
2026-06-28 Improve gif preview performance, add viewer delete button and bottom info bar
2026-07-03 Add Buildroot package to build the native app
    The published firmware source had no recipe to compile src/ into
    /usr/bin/optocam_app, so a clean make produced an image with no camera
    app. Add package/optocam (Config.in + optocam.mk) and src/Makefile, wire
    BR2_PACKAGE_OPTOCAM into the defconfig, and document the repo->Buildroot
    path mapping and package registration in the README.
